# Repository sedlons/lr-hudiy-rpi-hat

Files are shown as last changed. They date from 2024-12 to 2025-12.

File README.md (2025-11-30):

## lr-hudiy-rpi-hat
RPi hat suitable for HUDIY. I used it in Land Rover Discovery II.

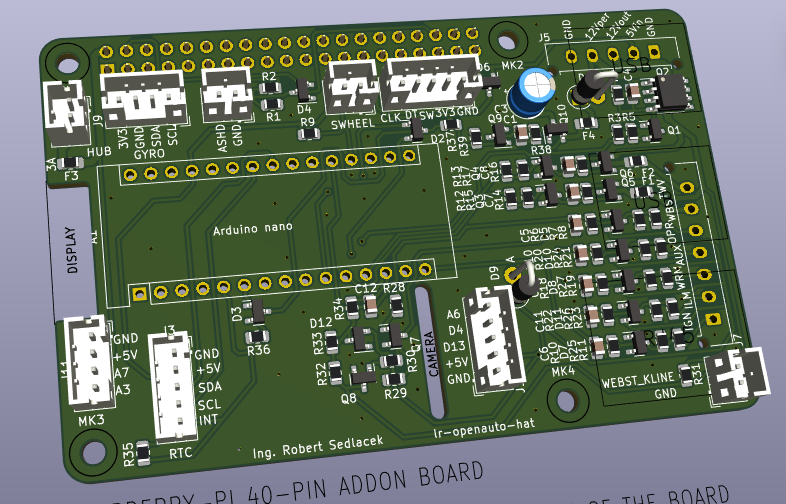
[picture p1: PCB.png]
PCB


Functions:
 - self power control with latch-up
 - steering wheel resistance button read
 - power control of RPi
 - rotary encoder (volume)
 - light sensor (control backlight/da/night mode)
 - heater power on by timing with RTC (NOT IMPLEMENTED IN HUDIY YET)
 - webasto RX/TX interface (NOT TESTED YET)
 - connector for I2C gyroscope for inclinometer (NOT IMPLEMENTED IN HUDIY YET)

Python code is used for communicating between HUDIY and arduino.

Old project name was lr-openauto-hat, because first version was used with OpenAuto.

## License

This project is licensed under the [GNU GPLv3](https://www.gnu.org/licenses/gpl-3.0.html).

- ✅ The code can be freely used, distributed, and modified.  
- 🔄 All modifications must be released under the same license.  
- ⚠️ This license does **not** prohibit commercial use.

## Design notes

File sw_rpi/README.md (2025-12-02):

# README

Install protobuf, websocket, websockets:
sudo apt install python3-protobuf python3-websocket python3-websocket

## Inlinometer plugin 

### Video example
Example (https://www.youtube.com/watch?v=qAAtmSkTd4U)

This plugin can be configured in settings.json. It is posible to set two alert values. When alert is on, whole 
html on hudiy blinks red / or stay completly red.

Copy hudiy-inclinometer to /home/pi

Copy service hudiy-inclinometer.service to /etc/systemd/system/

Both service can be enabled / checked/  started with 
 - sudo systemctl enable hudiy-inclinometer
 - sudo systemctl start hudiy-inclinometer
 - systemctl status hudiy-inclinometer

### Add inclinometer to hudiy dash

edit file 
~/.hudiy/share/config/dashboards.json 
Example with inclinometer instead of phone

```
{
    "dashboards": [
        {
            "isDefault": true,
            "action": "hudiy_dashboard",
            "widgets": [
                {
                    "type": "date_time",
                    "size": "small_narrow"
                },
                {
                    "type": "navigation",
                    "size": "medium_narrow"
                },
                {
                    "type": "now_playing",
                    "size": "large_narrow"
                },
                {
                    "type": "web",
                    "size": "small_narrow",
                    "url": "file:///home/pi/hudiy-inclinometer/hudiy-inclinometer.html"
                }
            ]
        }
    ]
}

```

## volume-encoder and communication with arduino (steering-wheel, light-sensor...)

Copy folder hudiy-discovery2 to /home/pi/, because these paths are used in systemd services.

Copy services hudiy-car-interface.service and encoder-volume.service to /etc/systemd/system/
Both services can be enabled and started with systemctl

shutdown command must be enabled to run by user pi. So run command "sudo visudo" and add to the end:
pi ALL=(ALL) NOPASSWD: /sbin/shutdown, /sbin/poweroff, /sbin/reboot

If not exist yet, create new file in udev:
/etc/udev/rules.d/99-hudiy.rules

and add:

SUBSYSTEM=="usb", ATTR{idVendor}=="*", ATTR{idProduct}=="*", MODE="0666", GROUP="plugdev"

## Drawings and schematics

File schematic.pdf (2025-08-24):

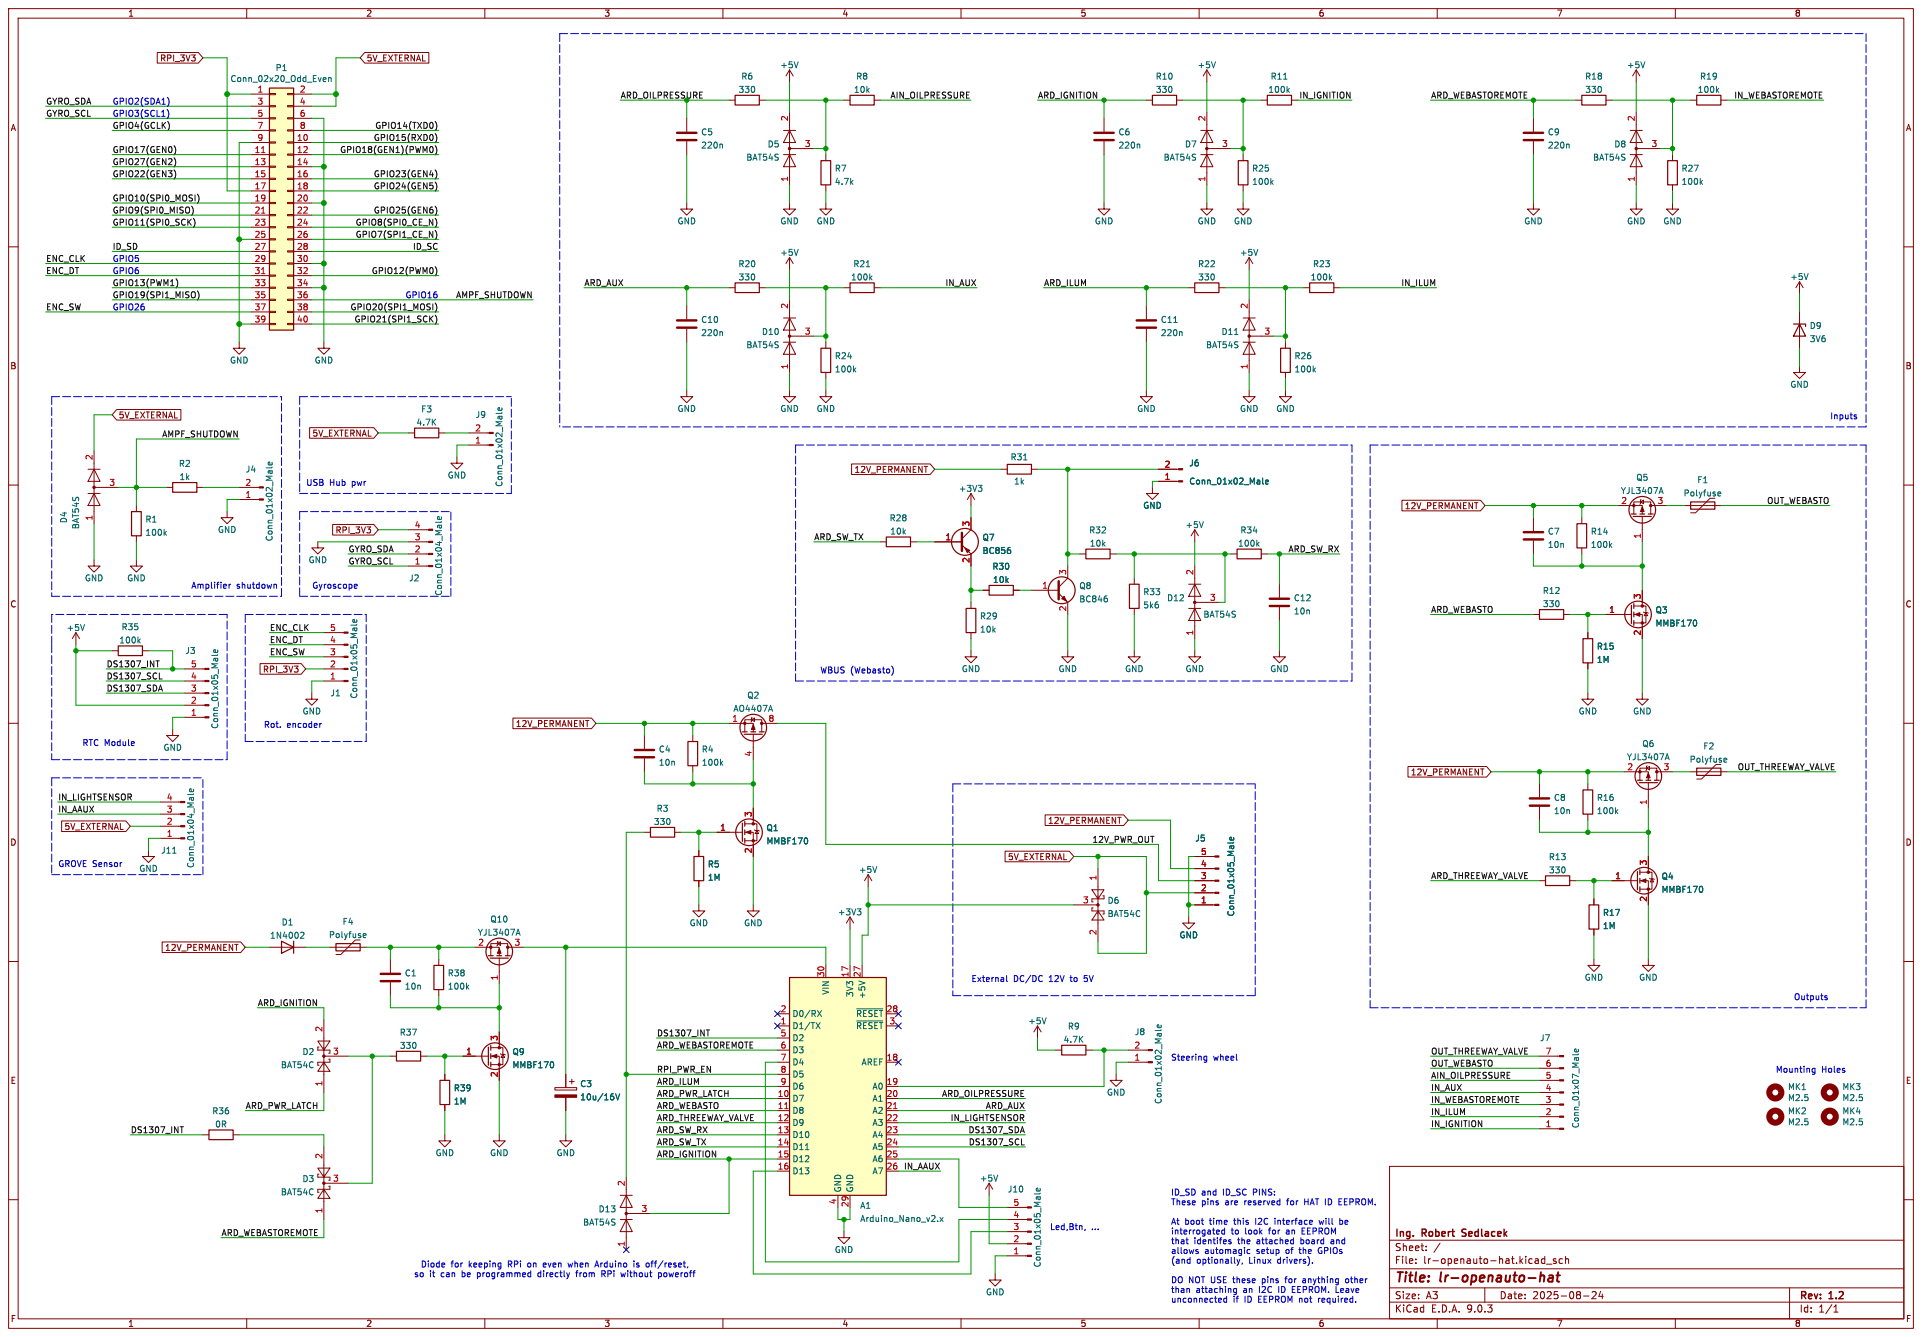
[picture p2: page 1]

Id: 1/1 Title: lr-openauto-hat File: lr-openauto-hat.kicad_sch Sheet: /

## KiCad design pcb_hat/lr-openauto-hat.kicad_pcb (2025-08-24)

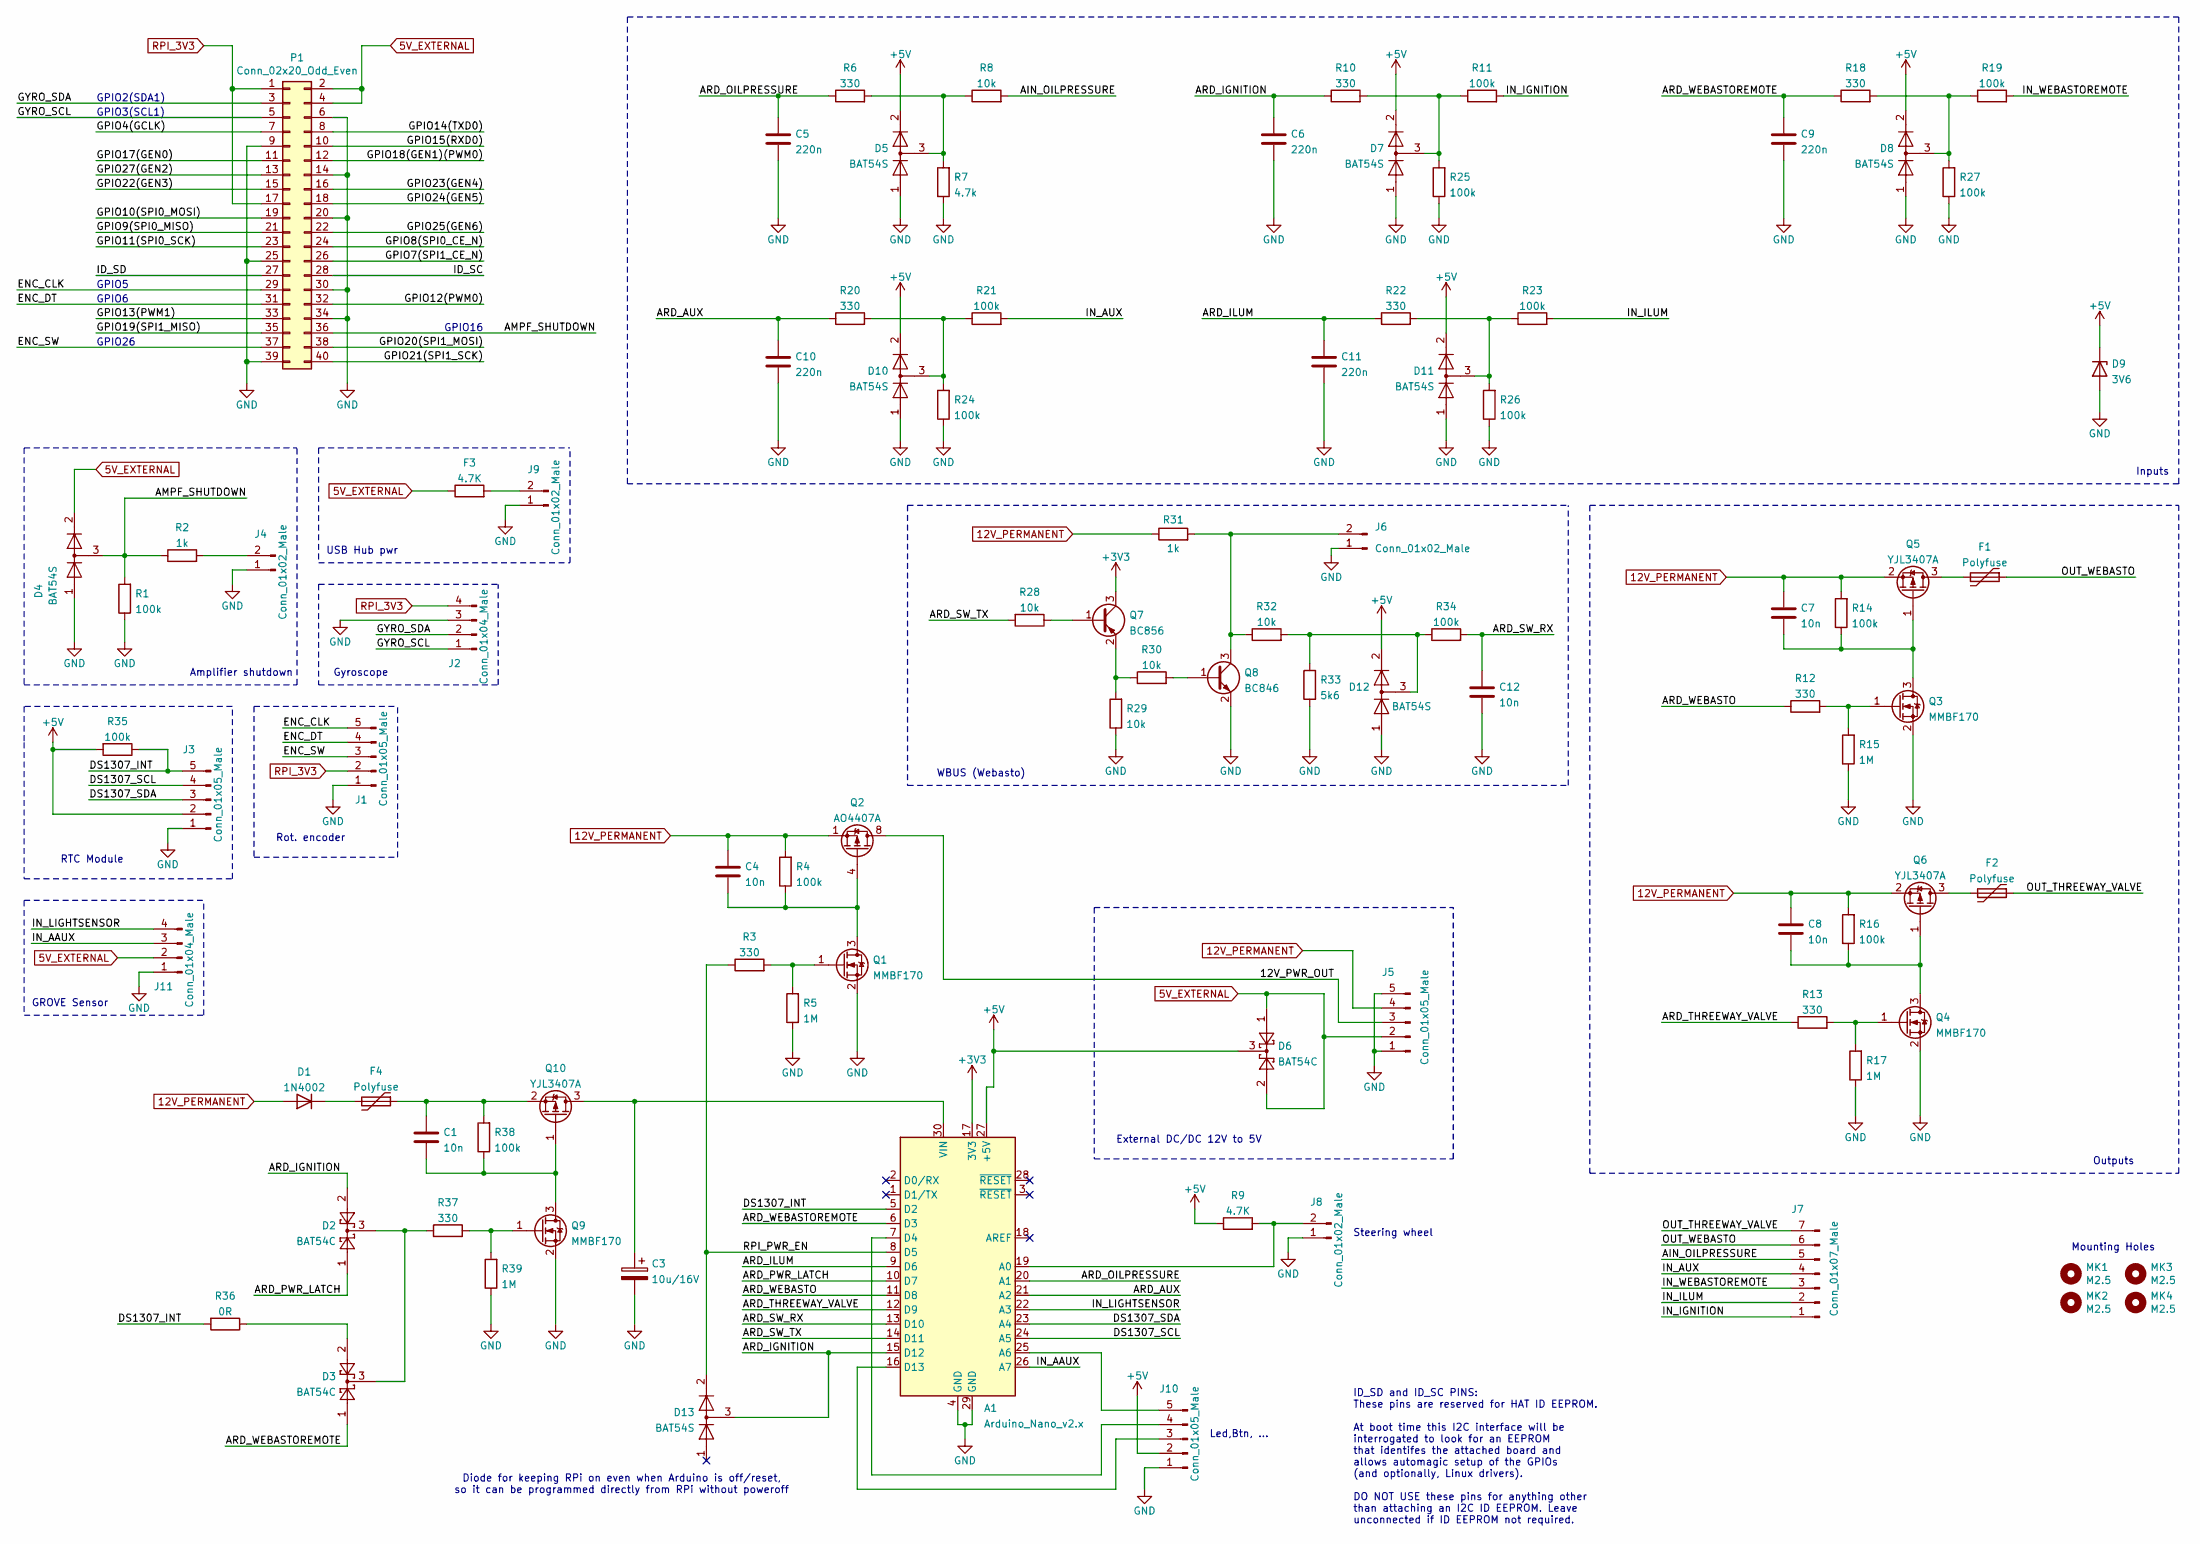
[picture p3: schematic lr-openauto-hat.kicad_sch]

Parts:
A1: Arduino_Nano_v2.x; Arduino_Nano
C1, C4, C7, C8, C12: 10n; C_0805_2012Metric
C3: 10u/16V; CP_Radial_D5.0mm_P2.50mm
C5, C6, C9, C10, C11: 220n; C_0805_2012Metric
D1: 1N4002; D_DO-41_SOD81_P2.54mm_Vertical_AnodeUp
D2, D3, D6: BAT54C; SOT-23
D4, D5, D7, D8, D10, D11, D12, D13: BAT54S; SOT-23
D9: 3V6; D_DO-41_SOD81_P2.54mm_Vertical_AnodeUp
F1, F2, F4: Polyfuse; Fuse_0805_2012Metric_Pad1.15x1.40mm_HandSolder
F3: 4.7K; R_0805_2012Metric_Pad1.20x1.40mm_HandSolder
J1, J3, J10: Conn_01x05_Male; JST_PH_B5B-PH-K_1x05_P2.00mm_Vertical
J2, J11: Conn_01x04_Male; JST_PH_B4B-PH-K_1x04_P2.00mm_Vertical
J4, J6, J8, J9: Conn_01x02_Male; JST_PH_B2B-PH-K_1x02_P2.00mm_Vertical
J5: Conn_01x05_Male; Molex_Micro-Fit_3.0_43650-0515_1x05_P3.00mm_Vertical
J7: Conn_01x07_Male; Molex_Micro-Fit_3.0_43650-0715_1x07_P3.00mm_Vertical
MK1, MK2, MK3, MK4: M2.5; MountingHole_2.7mm_M2.5
P1: Conn_02x20_Odd_Even; PinSocket_2x20_P2.54mm_Vertical
Q1, Q3, Q4, Q9: MMBF170; SOT-23
Q2: AO4407A; SOIC-8_3.9x4.9mm_P1.27mm
Q5, Q6, Q10: YJL3407A; SOT-23
Q7: BC856; SOT-23
Q8: BC846; SOT-23
R1, R4, R11, R14, R16, R19, R21, R23, R24, R25, R26, R27, R34, R35, R38: 100k; R_0805_2012Metric
R2, R31: 1k; R_0805_2012Metric
R3, R6, R10, R12, R13, R18, R20, R22, R37: 330; R_0805_2012Metric
R5, R15, R17, R39: 1M; R_0805_2012Metric
R7: 4.7k; R_0805_2012Metric
R8, R28, R29, R30, R32: 10k; R_0805_2012Metric
R9: 4.7K; R_0805_2012Metric
R33: 5k6; R_0805_2012Metric
R36: 0R; R_0805_2012Metric

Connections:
5V_EXTERNAL: D4.2 (A), D6.1, D6.2, F3.1, J5.2, J11.2, P1.2, P1.4
12V_PERMANENT: C4.1, C7.1, C8.1, D1.2 (A), J5.4, Q2.1 (S), Q2.2 (S), Q2.3 (S), Q5.2 (S), Q6.2 (S), R4.2, R14.2, R16.2, R31.1
+3V3: A1.17 (3V3), Q7.3 (C)
+5V: A1.27 (+5V), D5.2 (A), D6.3, D7.2 (A), D8.2 (A), D9.1 (K), D10.2 (A), D11.2 (A), D12.2 (A), J3.2, J10.2, R9.1, R35.2
/12V_PWR_OUT: J5.3, Q2.5 (D), Q2.6 (D), Q2.7 (D), Q2.8 (D)
/AIN_OILPRESSURE: J7.5, R8.2
/AMPF_SHUTDOWN: D4.3 (K), P1.36, R1.2, R2.1
/ARD_AUX: A1.21 (A2), C10.1, R20.1
/ARD_IGNITION: A1.15 (D12), C6.1, D2.2, D13.3 (K), R10.1
/ARD_ILUM: A1.9 (D6), C11.1, R22.1
/ARD_OILPRESSURE: A1.20 (A1), C5.1, R6.1
/ARD_PWR_LATCH: A1.10 (D7), D2.1
/ARD_SW_RX: A1.13 (D10), C12.1, R34.2
/ARD_SW_TX: A1.14 (D11), R28.2
/ARD_THREEWAY_VALVE: A1.12 (D9), R13.1
/ARD_WEBASTO: A1.11 (D8), R12.1
/ARD_WEBASTOREMOTE: A1.6 (D3), C9.1, D3.1, R18.1
/DS1307_INT: A1.5 (D2), J3.5, R35.1, R36.2
/DS1307_SCL: A1.24 (A5), J3.4
/DS1307_SDA: A1.23 (A4), J3.3
/ENC_CLK: J1.5, P1.29
/ENC_DT: J1.4, P1.31
/ENC_SW: J1.3, P1.37
/GPIO4(GCLK): P1.7
/GPIO7(SPI1_CE_N): P1.26
/GPIO8(SPI0_CE_N): P1.24
/GPIO9(SPI0_MISO): P1.21
/GPIO10(SPI0_MOSI): P1.19
/GPIO11(SPI0_SCK): P1.23
/GPIO12(PWM0): P1.32
/GPIO13(PWM1): P1.33
/GPIO14(TXD0): P1.8
/GPIO15(RXD0): P1.10
/GPIO17(GEN0): P1.11
/GPIO18(GEN1)(PWM0): P1.12
/GPIO19(SPI1_MISO): P1.35
/GPIO20(SPI1_MOSI): P1.38
/GPIO21(SPI1_SCK): P1.40
/GPIO22(GEN3): P1.15
/GPIO23(GEN4): P1.16
/GPIO24(GEN5): P1.18
/GPIO25(GEN6): P1.22
/GPIO27(GEN2): P1.13
/GYRO_SCL: J2.1, P1.5
/GYRO_SDA: J2.2, P1.3
/ID_SC: P1.28
/ID_SD: P1.27
/IN_AAUX: A1.26 (A7), J11.3
/IN_AUX: J7.4, R21.2
/IN_IGNITION: J7.1, R11.2
/IN_ILUM: J7.2, R23.2
/IN_LIGHTSENSOR: A1.22 (A3), J11.4
/IN_WEBASTOREMOTE: J7.3, R19.2
/OUT_THREEWAY_VALVE: F2.1, J7.7
/OUT_WEBASTO: F1.1, J7.6
/RPI_PWR_EN: A1.8 (D5), D13.2 (A), R3.1
GND: A1.4 (GND), A1.29 (GND), C3.2, C5.2, C6.2, C9.2, C10.2, C11.2, C12.2, D4.1 (K), D5.1 (K), D7.1 (K), D8.1 (K), D9.2 (A), D10.1 (K), D11.1 (K), D12.1 (K), J1.1, J2.3, J3.1, J4.1, J5.1, J5.5, J6.1, J8.1, J9.1, J10.1, J11.1, P1.6, P1.9, P1.14, P1.20, P1.25, P1.30, P1.34, P1.39, Q1.2 (S), Q3.2 (S), Q4.2 (S), Q8.2 (E), Q9.2 (S), R1.1, R5.1, R7.1, R15.1, R17.1, R24.1, R25.1, R26.1, R27.1, R29.1, R33.2, R39.1
unnamed: A1.19 (A0), J8.2, R9.2
unnamed: A1.25 (A6), J10.5
unnamed: A1.7 (D4), J10.4
unnamed: A1.16 (D13), J10.3
unnamed: A1.30 (VIN), C3.1, Q10.3 (D)
unnamed: D1.1 (K), F4.2
unnamed: D2.3, D3.3, R37.1
unnamed: D3.2, R36.1
unnamed: D5.3 (K), R6.2, R7.2, R8.1
unnamed: D7.3 (K), R10.2, R11.1, R25.2
unnamed: D8.3 (K), R18.2, R19.1, R27.2
unnamed: D10.3 (K), R20.2, R21.1, R24.2
unnamed: D11.3 (K), R22.2, R23.1, R26.2
unnamed: D12.3 (K), R32.2, R33.1, R34.1
unnamed: J4.2, R2.2
unnamed: J6.2, Q8.3 (C), R31.2, R32.1
unnamed: F3.2, J9.2
unnamed: C4.2, Q1.3 (D), Q2.4 (G), R4.1
unnamed: Q1.1 (G), R3.2, R5.2
unnamed: C7.2, Q3.3 (D), Q5.1 (G), R14.1
unnamed: Q3.1 (G), R12.2, R15.2
unnamed: C8.2, Q4.3 (D), Q6.1 (G), R16.1
unnamed: Q4.1 (G), R13.2, R17.2
unnamed: F1.2, Q5.3 (D)
unnamed: F2.2, Q6.3 (D)
unnamed: Q7.1 (B), R28.1
unnamed: Q7.2 (E), R29.2, R30.1
unnamed: Q8.1 (B), R30.2
unnamed: Q9.1 (G), R37.2, R39.2
unnamed: C1.2, Q9.3 (D), Q10.1 (G), R38.1
unnamed: C1.1, F4.1, Q10.2 (S), R38.2
RPI_3V3: J1.2, J2.4, P1.1, P1.17

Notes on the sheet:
RTC Module
GROVE Sensor
ID_SD and ID_SC PINS: These pins are reserved for HAT ID EEPROM. At boot time this I2C interface will be interrogated to look for an EEPROM that identifes the attached board and allows automagic setup of the GPIOs (and optionally, Linux drivers). DO NOT USE these pins for anything other than attach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
GPIO5
Outputs
Gyroscope
Amplifier shutdown
GPIO26
Led,Btn, ...
External DC/DC 12V to 5V
GPIO3(SCL1)
Steering wheel
GPIO6
Mounting Holes
Diode for keeping RPi on even when Arduino is off/reset, so it can be programmed directly from RPi without poweroff
USB Hub pwr
GPIO2(SDA1)
Inputs
WBUS (Webasto)
Rot. encoder
GPIO16

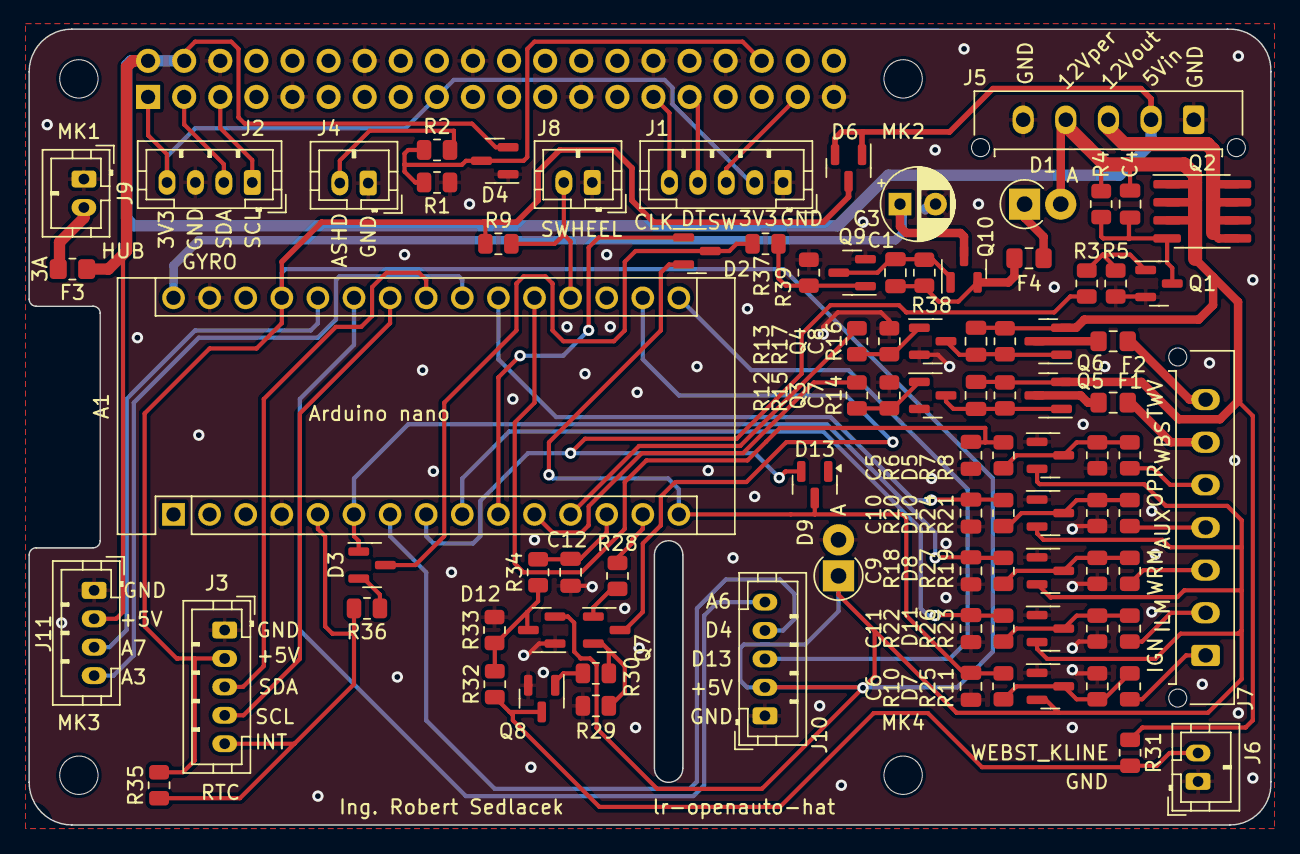
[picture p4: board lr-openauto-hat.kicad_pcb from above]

Board: 2 copper layers, 87.4 x 56.0 mm, 94 parts (1 on the bottom side), 67 nets.

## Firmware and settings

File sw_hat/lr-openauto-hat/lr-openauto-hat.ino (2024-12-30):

/*
 * 
 * lr-openauto-hat
 *
 *   Author: Ing. Robert Sedlacek
 *   Date: February 2022
 *
 */

#include <avr/wdt.h>

/* Input/output/analog pin definitions */
#define PIN_D4           4  /* */
#define PIN_RPI_PWR_EN   5  /* output-enable rpi power */
#define PIN_ILUM         6  /* */
#define PIN_PWR_LATCH    7  /* output-latching power */
#define PIN_WEBASTO      8  /* */
#define PIN_THR_VALVE    9  /* */
#define PIN_SW_RX        10 /* */
#define PIN_SW_TX        11 /* */
#define PIN_IGNITION     12 /* */
#define PIN_D13          13 /* */
#define PIN_STEER_WHL    A0 /* */
#define PIN_OIL_PRESS    A1 /* */
#define PIN_AUX          A2 /* */
#define PIN_LIGHT_SENS   A3 /* */
#define PIN_DS1307_SDA   A4 /* */
#define PIN_DS1307_SCL   A5 /* */
#define PIN_A6           A6 /* */
#define PIN_AAUX         A7 /* */

/*------------------------------------------------------------------------------------------------------*/
/*  MACRO's  */
/*------------------------------------------------------------------------------------------------------*/
/* Simple period */
#define TASK_PERIOD(__NAME__, __PERIOD__) static unsigned long __NAME__##LastTime=0; for(;millis() - __NAME__##LastTime > __PERIOD__; __NAME__##LastTime=millis())
/* Defining wheel button resistance */
#define WHEEL_BTN_RES(__RES__) {__RES__, 0, 0}
/*------------------------------------------------------------------------------------------------------*/
/*  VARIABLES - GLOBAL  */
/*------------------------------------------------------------------------------------------------------*/
/* State variable */
struct {
  struct {
    int ignition;          /* State of ignition pin */
    int steer_whl_btn;     /* Steering wheel button reconstructed from analog value */
  } in;
  struct {
    int rpi_pwr_en;
    int webasto;
  } out;
  struct {
    unsigned long last_ignition_change;
  } timestamps;
  struct {
    unsigned int light_sens;
    unsigned int oil_press;
    unsigned int steer_whl;   /* Analog value from steering wheel buttons */
  } analog;
  struct {
    bool webasto_on_rpi_off;
    bool webasto_on_rpi_on;
    unsigned int webasto_set_on; /* On time in minutes */
    unsigned int webasto_set_off; /* Off time in minutes */
    unsigned int webasto_set_cycles; /* Number of ON cycles */
  } remote;
} state;
/*------------------------------------------------------------------------------------------------------*/
/* Settings */
struct {
  int shutdown_delay_cmdRpi;      /* sec */    /* Poweroff command for RPi delay after IGN off */
  int shutdown_delay_pwrRpi;      /* sec */    /* Shutdown of RPi delay after IGN off */
  int shutdown_delay_arduino;  /* sec */    /* Shutdown of Arduino delay after IGN off */
  float light_sensor_filter;
  float steer_whl_filter;
} settings;
/*------------------------------------------------------------------------------------------------------*/
/* Pre fill threshold values etc. based on button resistance array */
void setup_steering_wheel_button_calc(void);
/* Steering wheel buttons struct for distinction */
typedef struct wheel_btn{ 
  float ohm;  /* Button resistor value in ohm */
  int lthr;   /* AD value - low threshold */
  int ad;     /* AD value (0-1024) */
  int hthr;   /* AD value - upper threshold */
} wheel_btn;
/* Array of structs with steering wheel resistances. Must be in ascending order */
wheel_btn resistances[] = {
  /* 0 - volume down */ WHEEL_BTN_RES(0),         
  /* 1 - volume up */   WHEEL_BTN_RES(390),       
  /* 2 - search up */   WHEEL_BTN_RES(390 + 470),   
  /* 3 - search down */ WHEEL_BTN_RES(390 + 470 + 820),
  /* 4 - mode */        WHEEL_BTN_RES(390 + 470 + 820 + 1000),
  /* 5 - end */         WHEEL_BTN_RES(390 + 470 + 820 + 1000 + 1000),
};
/* Length of resistances */
const int resistance_len = sizeof(resistances) / sizeof(wheel_btn);
/*------------------------------------------------------------------------------------------------------*/
/*  SETUP  */
/*------------------------------------------------------------------------------------------------------*/
void setup() {
  /* Arduino power latch first after ignition on */
  pinMode(PIN_PWR_LATCH, OUTPUT);
  digitalWrite(PIN_PWR_LATCH, HIGH);
  delay(3);

  /* Clear all state variables */
  memset(&state, 0, sizeof(state));

  /* Configure outputs */
  pinMode(PIN_RPI_PWR_EN, INPUT);
  //digitalWrite(PIN_RPI_PWR_EN, HIGH);
  
  pinMode(PIN_THR_VALVE, OUTPUT);
  digitalWrite(PIN_THR_VALVE, LOW);
  
  pinMode(PIN_WEBASTO, OUTPUT);
  digitalWrite(PIN_WEBASTO, LOW);
  
  pinMode(LED_BUILTIN, OUTPUT);

  /* Configure inputs */
  pinMode(PIN_ILUM, INPUT);
  pinMode(PIN_IGNITION, INPUT);
  //pinMode(PIN_STEER_WHL, INPUT);
  pinMode(PIN_OIL_PRESS, INPUT);
  //pinMode(PIN_LIGHT_SENS, INPUT);

  /* USB to serial port for debuging */
  Serial.begin(115200);

  /* DEFAULT Settings */
    /* TODO: Move to eeprom */
  settings.shutdown_delay_arduino    = 5 * 60; /* 5 minutes */
  settings.shutdown_delay_pwrRpi     = 4 * 60; /* 4 minutes MUST BE LOWER THAN shutdown_delay_arduino */
  settings.shutdown_delay_cmdRpi     = 2 * 60; /* 2 minutes MUST BE LOWER THAN shutdown_delay_pwrRpi */
  settings.light_sensor_filter       = 0.005f; /* Light sensor analog value filter (0.0 - 1.0) */
  settings.steer_whl_filter          = 0.05f;

  setup_steering_wheel_button_calc();

  /* Say hello */
  Serial.println("lr-openauto-hat v1.0");

  wdt_enable(WDTO_4S);
}
/*------------------------------------------------------------------------------------------------------*/
void setup_steering_wheel_button_calc(void) {
  /* Onboard pullup resistor value */
  const float res_R9 = 4300; /* ohm */
  
  /* Prefill */
  for (int i = 0; i < resistance_len; i++) {
    resistances[i].ad = 1024.0f * resistances[i].ohm / (resistances[i].ohm + res_R9);
    
    float part = 0.1*(float)resistances[i].ad;
    resistances[i].lthr = resistances[i].ad - part;
    resistances[i].hthr = resistances[i].ad + part;

    Serial.print("Steering wheel disctinction:");
    Serial.print((int)resistances[i].ohm, DEC); 
    Serial.print(": "); 
    Serial.print(resistances[i].lthr, DEC);
    Serial.print("<");
    Serial.print(resistances[i].ad, DEC);
    Serial.print(">"); 
    Serial.println(resistances[i].hthr, DEC);
  }
}

/*------------------------------------------------------------------------------------------------------*/
/*  INPUT read  */
/* Input read with debouncing etc. */
/*------------------------------------------------------------------------------------------------------*/
void input_read(void) {
  /* If change of IGN pin occured, update timestamp */
  if(digitalRead(PIN_IGNITION) != state.in.ignition) {
    state.in.ignition = digitalRead(PIN_IGNITION);
    state.timestamps.last_ignition_change = millis();
    Serial.print("Ignition: ");
    if(state.in.ignition) {
      Serial.println("on");  
    } else {
      Serial.println("off");  
    }
  }

  /* Light sensor */
  state.analog.light_sens = settings.light_sensor_filter * (float)analogRead(PIN_LIGHT_SENS) + (1.0f - settings.light_sensor_filter) * state.analog.light_sens;

  /* Light sensor */
  state.analog.steer_whl = settings.steer_whl_filter * (float)analogRead(PIN_STEER_WHL) + (1.0f - settings.steer_whl_filter) * state.analog.steer_whl;
}
/*------------------------------------------------------------------------------------------------------*/
/* Receive data from serial port */
/*
 * Priklad: N,30,60,4\n
 * N - Rpi se vypne, 30min bufik on, 60min off, 4x
 */
void parse_received_line(char *buf) {
  unsigned int auxOn,auxOff,auxCycles;
  char * strtokIndx; /* This is used by strtok() as an index */

  Serial.println(buf);
  char cmd = buf[0];

  strtokIndx = strtok(buf,",");      /* Jump over first cmd part */
 
  strtokIndx = strtok(NULL, ","); // this continues where the previous call left off
  auxOn = atoi(strtokIndx);

  strtokIndx = strtok(NULL, ",");
  auxOff = atoi(strtokIndx);

  strtokIndx = strtok(NULL, ",");
  auxCycles = atoi(strtokIndx);

  /* Validity check */
  if (auxOn  < 5    ||
      auxOff < 5    ||
      auxOn  > 3600 ||
      auxOff > 3600) {
    Serial.println("Warning: Time must be between 5 and 3600 minutes");
    return;
  }

  if(auxCycles < 1 || auxCycles > 20) {
    Serial.println("Warning: Cycles must be between 1 and 20");
    return;    
  }

  switch(cmd) {
    case 'N': //Night heating
      state.remote.webasto_on_rpi_off = true;
      Serial.print("Webasto night mode ON");
      break;
    case 'M': //Movie with heating
      state.remote.webasto_on_rpi_on = true;
      Serial.print("Webasto movie mode ON");
      break;
    default:
      Serial.println("Warning: Unknown command");
      return;
  }

  state.remote.webasto_set_on = auxOn;
  state.remote.webasto_set_off = auxOff;
  state.remote.webasto_set_cycles = auxCycles;

  Serial.print(" - On:");
  Serial.print(state.remote.webasto_set_on, DEC);
  Serial.print("min, Off:");
  Serial.print(state.remote.webasto_set_off, DEC);
  Serial.print("min, On:");
  Serial.print(state.remote.webasto_set_cycles, DEC);
  Serial.println("x");
}
/*------------------------------------------------------------------------------------------------------*/
/* Receive data from serial port */
void remote_receive_serial(void) {
  const byte buffLen = 32; /* Size of receive serial buffer (for each line) */
  static char receivedChars[buffLen];   /* An array to store the received data */

  static byte ndx = 0;
  char endMarker = '\n'; /* 0x0D-CarriageReturn  0x0A-NewLine  */
  char rc;
    
  while (Serial.available() > 0) {
  rc = Serial.read();
    if (rc != endMarker) {
      receivedChars[ndx] = rc;
      ndx++;
      if (ndx >= buffLen) {
        ndx = buffLen - 1;
      }
    } else {
      receivedChars[ndx] = '\0'; // terminate the string
      ndx = 0;

      /* Parse received line */
      parse_received_line(receivedChars);
    }
  }
}
/*------------------------------------------------------------------------------------------------------*/
/*  TASKS  */
/* Simplest tasking is used - every task must return quickly as posible. */
/*------------------------------------------------------------------------------------------------------*/
/* Arduino power managment */
void task_arduino_pwr(void) {
  if(state.in.ignition != HIGH) { /* Ignition off */
    unsigned long timeS = (millis() - state.timestamps.last_ignition_change) / 1000;

    /* Just leave arduino pwr on during movie watching */
    if(state.remote.webasto_on_rpi_on || state.remote.webasto_on_rpi_off) {
      return;
    }

    TASK_PERIOD(shArd,1000 /* ms */) {
      Serial.print("Shutdown in ");
      Serial.println(settings.shutdown_delay_arduino - timeS, DEC);
    }
    
    if(timeS > settings.shutdown_delay_arduino) {
      Serial.println("Cutting arduino PWR...");
      while(1){ /* Cycle end forever */
        digitalWrite(PIN_PWR_LATCH, LOW);
      }
    }
  } else { /* Ignition on */
    if(millis() - state.timestamps.last_ignition_change > 50) {
      /* Print text only when change */
      if(state.out.rpi_pwr_en != HIGH) {
        Serial.println("RPi power ON"); 
      }
      state.out.rpi_pwr_en = HIGH;
    }    
  }
}
/*------------------------------------------------------------------------------------------------------*/
/* RPi power managment */
void task_rpi_pwr(void) {
  /* Just leave rpi during movie watching */
  if(state.remote.webasto_on_rpi_on) {
    return;
  }
  
  /* Turn off rpi, if ignition off and Pi already on */
  if(state.in.ignition != HIGH && state.out.rpi_pwr_en != LOW) {
    int timeS = (millis() - state.timestamps.last_ignition_change) / 1000;

    /* Send command to RPI for software off */
    if(timeS > settings.shutdown_delay_cmdRpi) {
      TASK_PERIOD(shRpi,3000 /* ms */) {
        Serial.println("RPi power OFF");
      }
    }

    /* Cut off power */
    if(timeS > settings.shutdown_delay_pwrRpi) {
      pinMode(PIN_RPI_PWR_EN, OUTPUT);
      state.out.rpi_pwr_en = LOW;
      delay(150);
      pinMode(PIN_RPI_PWR_EN, INPUT);
    }
  }  
}
/*------------------------------------------------------------------------------------------------------*/
/*  */
void task_light_sensor(void) {
  TASK_PERIOD(,1000 /* ms */) {
    Serial.print("Light sens: ");
    Serial.println(state.analog.light_sens, DEC);
  }
}
/*------------------------------------------------------------------------------------------------------*/
/*  */
void task_steering_wheel(void) {
  /* Send button info every x ms */
  TASK_PERIOD(btnsense, 200) {
    for(int i = 0; i < resistance_len; i++) {
      if(resistances[i].lthr >= state.analog.steer_whl && state.analog.steer_whl <= resistances[i].hthr) {
        Serial.print("Steer wheel btn: ");
        Serial.println(i, DEC);        
        break;
      }
    }
  }
  
  TASK_PERIOD(text,1000 /* ms */) {
    Serial.print("Steer wheel sens: ");
    Serial.println(state.analog.steer_whl, DEC);
  }
  
}
/*------------------------------------------------------------------------------------------------------*/
/*  */
void task_oil_pressure(void) {
  
}
/*------------------------------------------------------------------------------------------------------*/
/*  */
void task_ilumination(void) {
  
}
/*------------------------------------------------------------------------------------------------------*/
/*  */
void task_communication(void) {
  
}
/*------------------------------------------------------------------------------------------------------*/
/*  */
void task_webasto_heating(void) {
  static bool isPause = false; /* True if off cycle */
  static int ccycle = 0; /* Current cycle */

  static unsigned long webOnLastTime=0;
  static unsigned long webOffLastTime=0;  

  /* Do nothing if on is not set */
  if(!(state.remote.webasto_on_rpi_on || state.remote.webasto_on_rpi_off)) {
    state.out.webasto = LOW;
    ccycle = 0;
    isPause = false;
    return;
  }

  /* If first cycle, init time variables, ... */
  if(ccycle == 0) {
    ccycle=1;
    webOnLastTime = millis();
    webOffLastTime = millis();
  }

  /* Main webasto timer control */
  if(isPause) {
    state.out.webasto = LOW;
    for(;millis() - webOffLastTime > 1000ul*60ul*state.remote.webasto_set_off; webOffLastTime=millis()) {
      //ccycle++;
      webOnLastTime = millis();
      isPause = false;
    }
  } else {
    state.out.webasto = HIGH;
    for(;millis() - webOnLastTime > 1000ul*60ul*state.remote.webasto_set_on; webOnLastTime=millis()) {
      ccycle++;
      webOffLastTime = millis();
      isPause = true;
    }
  }

  /* Last cycle, turn off all */
  if(ccycle > state.remote.webasto_set_cycles) {
    state.remote.webasto_on_rpi_on = false;
    state.remote.webasto_on_rpi_off = false;
    state.out.webasto = LOW;
    isPause = false;
    ccycle = 0;
  }
}
/*------------------------------------------------------------------------------------------------------*/
/* Just Arduino onboard led blinking - shared with D13 ! */
void task_led_blink(void) {
static int last = HIGH;
  TASK_PERIOD(,150 /* ms */) {
    digitalWrite(LED_BUILTIN, last);
    if(last == HIGH) {
      last = LOW;
    } else {
      last = HIGH;
    }  
  } /* TASK_PERIOD_END */
}

/*------------------------------------------------------------------------------------------------------*/
/*  OUTPUT write  */
/* Writing outputs, serial outputs, etc. */
/*------------------------------------------------------------------------------------------------------*/
void output_write(void) {
  /* Rpi power */
  digitalWrite(PIN_RPI_PWR_EN, state.out.rpi_pwr_en);
  /* Webasto control */
  digitalWrite(PIN_WEBASTO, state.out.webasto);

  TASK_PERIOD(outInfo,1000 /* ms */) {
    Serial.print("Webasto: ");
    Serial.println((state.out.webasto) ? "ON" : "Off");
  }
}

/*------------------------------------------------------------------------------------------------------*/
/*  LOOP  */
/* Loop like in PLCs. Load inputs first, then tasks and write to outputs at the end. */
/*------------------------------------------------------------------------------------------------------*/
void loop() {
  /* Reset watchdog*/
  wdt_reset();
  /* Set up WDT interrupt */
  WDTCSR = (1 << WDCE) | (1 << WDE);
  /* Start watchdog timer with 4s prescaller */
  WDTCSR = (1 << WDIE) | (1 << WDE) | (1 << WDP3) | (1 << WDP0);
  
  input_read();
  remote_receive_serial();
  
  task_arduino_pwr();
  task_rpi_pwr();
  task_light_sensor();
  task_steering_wheel();
  task_oil_pressure();
  task_ilumination();
  task_communication();
  task_webasto_heating();
  task_led_blink();
  
  output_write();
}

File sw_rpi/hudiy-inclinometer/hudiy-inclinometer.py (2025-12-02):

#!/usr/bin/env python3
import os, sys, json, asyncio, signal, math
import subprocess, venv, contextlib
from typing import Set
import time
import websockets
from websockets.legacy.server import WebSocketServerProtocol, serve
import smbus2

# ----------------- Configuration -----------------
HOST = "0.0.0.0"
PORT = 8765
BUS_NUM = 1
I2C_ADDR = 0x68
FAST_INTERVAL = 0.01 # Fast reading interval of I2C sensor
PUBLISH_INTERVAL = 0.4   # 5 Hz
DEBUG = True
CALIBRATION_FILE = "settings.json"

# ----------------- Globals -----------------
CLIENTS: Set[WebSocketServerProtocol] = set()
latest_data = {"roll":0.0, "pitch":0.0, "roll_alert":"none", "pitch_alert":"none"}
roll_filtered = 0.0
pitch_filtered = 0.0
alpha = 0.5  # complementary filter smoothing

# ----------------- Helper Functions -----------------
def load_calibration():
    if os.path.exists(CALIBRATION_FILE):
        with open(CALIBRATION_FILE,"r") as f: return json.load(f)
    return {
        "roll_alert_blink":15, "roll_alert_red":25,
        "pitch_alert_blink":10, "pitch_alert_red":20,
        "zero_roll":0.0, "zero_pitch":0.0
    }

bus = smbus2.SMBus(BUS_NUM)
# Wake up sensor
bus.write_byte_data(I2C_ADDR, 0x6B, 0)

def read_i2c_sensor():
    """
    Reads raw roll/pitch from the I2C sensor and applies zeroed offsets.
    Returns: roll, pitch in degrees
    """
    try:
        data = bus.read_i2c_block_data(I2C_ADDR, 0x3B, 6)  # Example: replace with your sensor
        acc_x = (data[0] << 8 | data[1])
        acc_y = (data[2] << 8 | data[3])
        acc_z = (data[4] << 8 | data[5])

        # Convert from 16-bit signed
        acc_x = acc_x if acc_x < 32768 else acc_x - 65536
        acc_y = acc_y if acc_y < 32768 else acc_y - 65536
        acc_z = acc_z if acc_z < 32768 else acc_z - 65536

        roll = math.degrees(math.atan2(acc_y, acc_z))
        pitch = math.degrees(math.atan2(-acc_x, math.sqrt(acc_y**2 + acc_z**2)))

    except Exception as e:
        print(f"[I2C] Read error: {e}", file=sys.stderr)


    return round(roll, 1), round(pitch, 1)


def compute_alert(value, blink_thresh, red_thresh):
    abs_val = abs(value)
    if abs_val >= red_thresh: return "red"
    if abs_val >= blink_thresh: return "blink"
    return "none"

async def sensor_loop(calib):
    global latest_data, roll_filtered, pitch_filtered
    while True:
        roll_raw, pitch_raw = read_i2c_sensor()
        roll = roll_raw - calib.get("zero_roll",0.0)
        pitch = pitch_raw - calib.get("zero_pitch",0.0)
        # complementary filter
        roll_filtered  = alpha * roll  + (1 - alpha) * roll_filtered
        pitch_filtered = alpha * pitch + (1 - alpha) * pitch_filtered
        # alerts
        roll_alert  = compute_alert(roll_filtered, calib["roll_alert_blink"], calib["roll_alert_red"])
        pitch_alert = compute_alert(pitch_filtered, calib["pitch_alert_blink"], calib["pitch_alert_red"])
        # store
        latest_data = {"roll":roll_filtered, "pitch":pitch_filtered,
                       "roll_alert":roll_alert, "pitch_alert":pitch_alert}
        await asyncio.sleep(FAST_INTERVAL)

# ----------------- WebSocket -----------------
async def broadcast(msg):
    if not CLIENTS: return
    text = json.dumps(msg)
    to_close = set()
    await asyncio.gather(*(safe_send(ws, text, to_close) for ws in list(CLIENTS)), return_exceptions=True)
    for ws in to_close: CLIENTS.discard(ws)

async def safe_send(ws, text, to_close):
    try: await ws.send(text)
    except: to_close.add(ws)

async def handler(ws):
    CLIENTS.add(ws)
    try:
        async for _ in ws: pass
    finally:
        CLIENTS.discard(ws)

async def producer_loop() -> None:
    while True:
        try:
            await broadcast(latest_data)
        except Exception as e:
            print(f"[producer] Error: {e}", file=sys.stderr)
        await asyncio.sleep(PUBLISH_INTERVAL)

async def main():
    loop = asyncio.get_running_loop()
    stop = loop.create_future()
    for sig in (signal.SIGINT, signal.SIGTERM):
        loop.add_signal_handler(sig, stop.set_result, None)
    async with serve(handler, HOST, PORT, ping_interval=20, ping_timeout=20):
        print(f"[WS] running on ws://{HOST}:{PORT}")
        sensor_task = asyncio.create_task(sensor_loop(calib))
        prod = asyncio.create_task(producer_loop())
        await stop
        sensor_task.cancel()
        prod.cancel()
        with contextlib.suppress(asyncio.CancelledError): 
            await sensor_task
            await prod

if __name__ == "__main__":
    calib = load_calibration()
    try: asyncio.run(main())
    except KeyboardInterrupt: pass

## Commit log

2024-12-30 Prvni commit
    [lr-openauto-hat.kicad_pcb, lr-openauto-hat.kicad_sch]
2025-08-24 Transition from openauto to hudiy
    [lr-openauto-hat.kicad_pcb, lr-openauto-hat.kicad_sch]
2025-11-30 encoder-volume modification for pipewire
